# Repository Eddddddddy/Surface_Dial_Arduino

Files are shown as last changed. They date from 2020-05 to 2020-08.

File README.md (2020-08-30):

# Surface_Dial_Arduino

Use attiny85 to achieve surface dial function

## **！注意！建议使用/PCB_with_gerber/Pro/...attiny v2 github.zip！其他pcb工程（包含立创EDA的开源工程）未经本人测试，不做可靠性保证。**

将这个添加到你的Arduino IDE开发板中：http://digistump.com/package_digistump_index.json

/bom.xlsx ：元器件清单

/lib ：arduino库

/src ：arduino代码（包含融丝恢复器代码）

/tools ：编程器上位机软件

/stl model ：3D打印模型

/PCB_with_gerber ：pcb文件

立创EDA开源文件在[这里](https://oshwhub.com/Lingling0408/project-dial-pcb)

【点个Star！】谢谢！

在[这里](https://www.bilibili.com/video/BV17K411W78w/)可以查看视频介绍

------

| | Pro | Lite |
| --- | --- | --- |
| **O&M** | @Eddddddddy | @Eddddddddy, @leostudiooo |
| **Basic Functions** | Y | Y |
| **Cost** | Higher | Lower |
| **Vibration(Taptic Engine)** | Y | N |
| **Encoder** | EC11E1834403 _(ALPS, without detent)_ | EC11*(With detent)* |
| **Arduino File** | /src/Surface_Dial_attiny.ino | /src/Surface_Dial_attiny_Lite.ino |
| **PCB File** _(Now All-in-One)_ | /PCB_with_gerber/Pro | /PCB_with_gerber/Lite |
| **Fuse Reset** | Needed | Unnecessary |

------

你需要做什么？

- 想好购买的元器件是Pro还是Lite *（虽然后期也可以升级）*

- 在你信任的地方购买所需元器件

- 焊接（见/PCB_with_Gerber/README.md)

- 刷入程序

- 开始你的Dial之旅

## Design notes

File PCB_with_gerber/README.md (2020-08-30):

# 二合一版本未经本人测试

# 关于版本选择和焊接 Version Choice & Soldering

## **！建议使用/PCB_with_gerber/Pro/...attiny v2 github.zip！**

## 版本选择 Version Chioce

| | Pro | Lite |
| --- | --- | --- |
| **O&M** | @Eddddddddy | @Eddddddddy, @leostudiooo |
| **Basic Functions** | Y | Y |
| **Cost** | Higher | Lower |
| **Vibration(Taptic Engine)** | Y | N |
| **Encoder** | EC11E1834403 _(ALPS, without detent)_ | EC11*(With detent)* |
| **Arduino File** | /src/Surface_Dial_attiny.ino | /src/Surface_Dial_attiny_Lite.ino |
| **PCB File** _(Now All-in-One)_ | /PCB_with_gerber/Pro | /PCB_with_gerber/Lite |
| **Fuse Reset** | Needed | Unnecessary |

## PCB

你可以选择原版Pro或Lite，也可以尝试新出来的二合一版本。
You can choose the original Pro or Lite, or the 2 in 1 ver.

## 焊接 Soldering (for 2 in 1 ver.)

如果你选择二合一版本，那么你有升级的机会。
If you choose the 2 in 1(AIO) version, you have a chance to upgrade to Pro.

- 如果你选择Pro，请连接板子背面标注SW Pro的两个焊盘。
If you choose Pro, plz connect the two solders with "SW Pro" on the bottom.

- 如果你选择Lite，请连接板子正面标注SW Lite的两个焊盘。
If you choose Lite, plz connect the two solders with "SW Lite" on the top.

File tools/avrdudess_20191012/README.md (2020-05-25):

AVRDUDESS - A GUI for AVRDUDE
=============================

This is a GUI for AVRDUDE ([http://savannah.nongnu.org/projects/avrdude](http://savannah.nongnu.org/projects/avrdude)).

[https://blog.zakkemble.net/avrdudess-a-gui-for-avrdude/](https://blog.zakkemble.net/avrdudess-a-gui-for-avrdude/)

AVRDUDESS pic

Windows:
--------
Requires .NET Framework 2.0 SP1 or newer. All systems since Windows Vista will have the required version already installed.

Linux & macOS:
-----------------
Can be ran using Mono ([http://www.mono-project.com](http://www.mono-project.com)).\
Has not been tested on macOS, but should work. Might need the `--arch=32` argument.

    mono --arch=32 avrdudess.exe

Installing on Ubuntu 18.04:
---------------------------
Install Mono (this is the minimum required, you can use `mono-complete` for a full install):

    sudo apt-get install libmono-system-windows-forms4.0-cil

On older versions of Ubuntu you might need to use `libmono-winforms2.0-cil` instead.

Install AVRDUDE and AVR-GCC (for avr-size):

    sudo apt-get install avrdude gcc-avr

Run AVRDUDESS with mono, you might have to run as root (sudo) so that AVRDUDE can access ports if you haven't changed any permissions or rules.d stuff:

    mono avrdudess.exe

Building:
---------
You will need Microsoft Visual Studio 2015 or newer installed (older might work too). Open `./src/avrdudess.sln` and click the 'Start' button at the top and it will build and run AVRDUDESS.\
You can find the output in `./src/avrdudess/bin/Debug/`, or `./src/avrdudess/bin/Release/` if you chose to build for Release (the drop down box second from the left of the Start button is where you can choose the configuration).

Making the Installer:
---------------------
You will need [Inno Setup](http://www.jrsoftware.org/isinfo.php) installed. Once you've used Visual Studio to build the Release version of AVRDUDESS, run `./installer/installer.bat` and the installer exe will appear in the same directory.

--------

Zak Kemble

contact@zakkemble.net

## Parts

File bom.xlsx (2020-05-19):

元器件名 | 数量
attiny85-20su soic8 | 1
ec11e1834403 | 1
usb type-c 母座 16p 沉板1.6mm | 1
0603 自恢复保险丝 0.5A 6v | 1
s0805 J3Y 三极管 SOT-23 | 1
0603 1.5k电阻 | 1
0603 4.7k电阻 | 3
0603 5.1k电阻 | 2
0603 66.5欧电阻 | 2
0603 0.1uf 电容 | 1
0603 4.7uf 电容 | 1
1206 3.6v 齐纳二极管 | 2
M2*6 平头螺丝 | 3
M4*8 圆头螺丝 | 3
0.5mm 硅胶防滑垫 | 5*5cm
48mm 铝合金旋钮帽 | 1
iPhone 7 taptic engine 线性马达 | 1

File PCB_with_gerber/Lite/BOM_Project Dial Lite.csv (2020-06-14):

ID | Name | Designator | Footprint | Quantity | Manufacturer Part | Manufacturer | Supplier | Supplier Part | value | 3DModel
1 | Comment | U?,U?,U?,U? | JUMPER | 4 |  |  |  |  | Comment | Jumper_5mm
2 | 3.6 Zener | U?,U? | LL34 | 2 |  |  |  |  | 3.6 Zener | LL-34_BD1.5-L3.5
3 | 500ma | U? | 0603R | 1 |  |  |  |  | 500ma | CircuitWorks - 0603-Resistor
4 | 5.1k | U?,U? | 0603R | 2 |  |  |  |  | 5.1k | CircuitWorks - 0603-Resistor
5 | 4.7K | U?,U?,U? | 0603R | 3 |  |  |  |  | 4.7K | CircuitWorks - 0603-Resistor
6 | 1.5k | U? | 0603R | 1 |  |  |  |  | 1.5k | CircuitWorks - 0603-Resistor
7 | 66.5 | U?,U? | 0603R | 2 |  |  |  |  | 66.5 | CircuitWorks - 0603-Resistor
8 | 4.7uF | U? | 0603C | 1 |  |  |  |  | 4.7uF | 0603c 100nf
9 | 0.1uF | U? | 0603C | 1 |  |  |  |  | 0.1uF | 0603c 100nf
10 | TYPE_C | USB1 | TYPE-C_A | 1 |  |  |  |  | TYPE_C | USB-C_SMD-TYPE-C-31-M-12
11 | EC11E1834403 | EC1 | SW-TH_EC11E1820402 | 1 |  |  |  |  | EC11 | EC11-5
12 | attiny85 | * | SOP8W | 1 |  |  |  |  | attiny85 | SW3dPS-SOIC8_(ATTINY12)

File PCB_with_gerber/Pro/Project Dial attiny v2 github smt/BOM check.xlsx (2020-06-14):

check | Name | Designator | Footprint | Quantity | value
1 | 3.6 Zener | U?,U? | LL34 | 2 | 3.6 Zener
1 | 500ma | U? | 0603R | 1 | 500ma
1 | 5.1k | U?,U? | 0603R | 2 | 5.1k
1 | 4.7K | U?,U?,U? | 0603R | 3 | 4.7K
1 | 1.5k | U? | 0603R | 1 | 1.5k
1 | 66.5 | U?,U? | 0603R | 2 | 66.5
1 | 4.7uF | U? | 0603C | 1 | 4.7uF
1 | 0.1uF | U? | 0603C | 1 | 0.1uF
1 | attiny85 | * | SOP8W | 1 | attiny85
1 | 1K | R4 | 0603R | 1 | 1K
1 | S8050 | Q1 | SOT-23 | 1 | S8050
1 | EC11E1834403 | EC1 | SW-TH_EC11E1820402 | 1 | EC11E1834403
1 | TYPE_C | USB1 | TYPE-C_A | 1 | TYPE_C

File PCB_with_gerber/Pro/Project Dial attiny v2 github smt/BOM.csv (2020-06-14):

ID | Name | Designator | Footprint | Quantity | Manufacturer Part | Manufacturer | Supplier | Supplier Part | value | 3DModel
1 | Comment | U?,U?,U?,U?,U? | JUMPER | 5 |  |  |  |  | Comment | Jumper_5mm
2 | 3.6 Zener | U?,U? | LL34 | 2 |  |  |  |  | 3.6 Zener | CircuitWorks - 0603-Resistor
3 | 500ma | U? | 0603R | 1 |  |  |  |  | 500ma | CircuitWorks - 0603-Resistor
4 | 5.1k | U?,U? | 0603R | 2 |  |  |  |  | 5.1k | CircuitWorks - 0603-Resistor
5 | 4.7K | U?,U?,U? | 0603R | 3 |  |  |  |  | 4.7K | CircuitWorks - 0603-Resistor
6 | 1.5k | U? | 0603R | 1 |  |  |  |  | 1.5k | CircuitWorks - 0603-Resistor
7 | 66.5 | U?,U? | 0603R | 2 |  |  |  |  | 66.5 | CircuitWorks - 0603-Resistor
8 | 4.7uF | U? | 0603C | 1 |  |  |  |  | 4.7uF | 0603c 100nf
9 | 0.1uF | U? | 0603C | 1 |  |  |  |  | 0.1uF | 0603c 100nf
10 | attiny85 | * | SOP8W | 1 |  |  |  |  | attiny85 | SW3dPS-SOIC8_(ATTINY12)
11 | 1K | R4 | 0603R | 1 |  |  |  |  | 1K | CircuitWorks - 0603-Resistor
12 | S8050 | Q1 | SOT-23 | 1 |  |  |  |  | S8050 | SOT-23-3L_L2.9-W1.6-H1.1-LS2.8-P0.95
13 | EC11E1834403 | EC1 | SW-TH_EC11E1820402 | 1 |  |  |  |  | EC11E1834403
14 | TYPE_C | USB1 | TYPE-C_A | 1 |  |  |  |  | TYPE_C | USB-C_SMD-TYPE-C-31-M-12
15 | Taptic Engine | R3 | 1812R | 1 |  |  |  |  | Taptic Engine

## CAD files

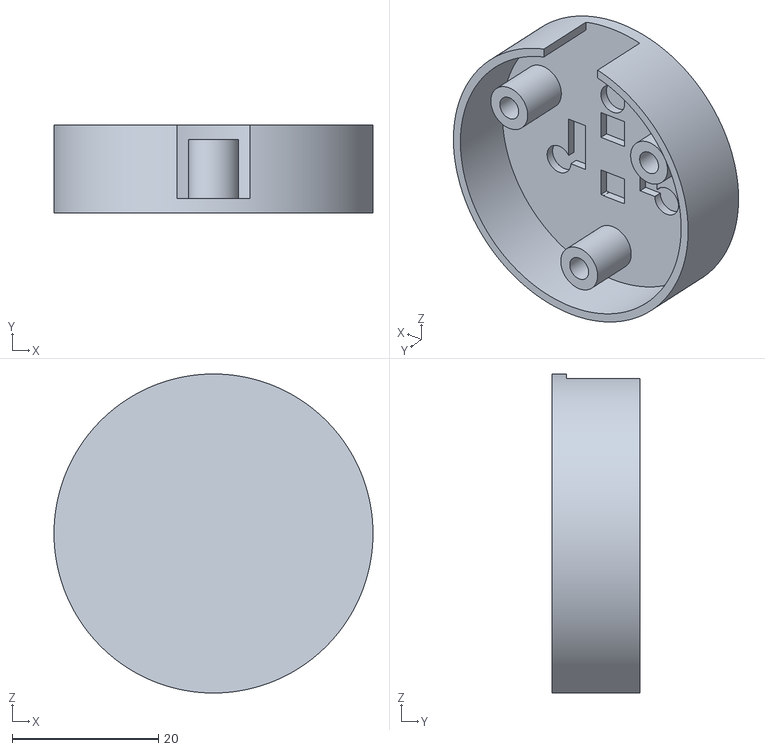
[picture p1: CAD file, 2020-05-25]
stl model/surface dial v2.3.STL
43.6 x 12.0 x 43.6

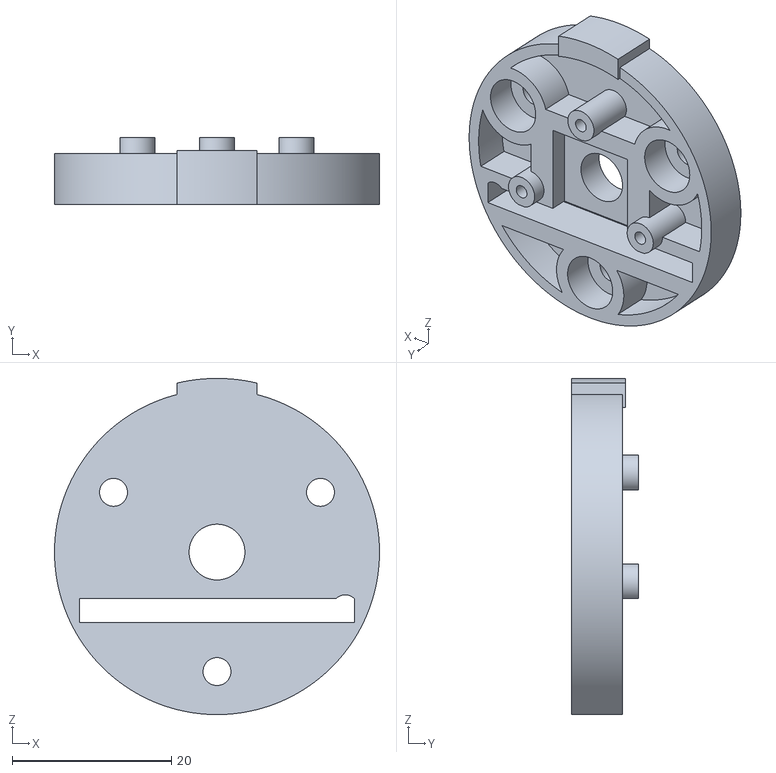
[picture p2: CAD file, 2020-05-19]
stl model/surface dial t v2.3.STL
40.8 x 8.40 x 42.2

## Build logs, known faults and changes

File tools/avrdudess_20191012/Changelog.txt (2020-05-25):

2019-10-12 (v2.11):
	- Fixed null exception if no MCU selected and "Set fuses" ticked
	- Updated Polish translation

2019-10-02 (v2.10):
	- Fix fuse read issue with MCUs that don't have all low, high and extended fuses
	- Update avrdude.conf to allow setting the CFD bit (Disable Clock Failure Detection) in the extended fuse for the ATmega328PB
	- Update URLs to HTTPS

2019-09-06 (v2.9):
	- Added French translation
	- Added Russian translation
	- Now shows full command line arguments in console output whenever avrdude is invoked
	- Fixed breaking click and drag anywhere to move window
	- Window title now shows "avrdude version UNKNOWN" instead of "?" if unable to find avrdude version

2019-02-09 (v2.8):
	- Added .NET 4.0+ to the list of supported runtimes, no longer need to install old .NET versions onto newer systems
	- Language selection box has been widened
	- New "About" box, now with clickable link
	- No longer creates temporary files when reading fuses and lock bits
	- LPT parallel port names in the port drop down box are now lower case
	- When resizing the main window, the controls on the right side are now also resized

2019-01-22 (v2.7):
	- Added Polish translation
	- Added Chinese translation
	- Added AVRDUDE support for ATmega328PB
	- Added displaying MCU signature near to the flash and EEPROM sizes
	- Fixed being unable to load xml file in the fuse bit selector window in Linux
	- Fixed flash and EEPROM file operation only being able to verify when a language other than English is chosen
	- All configuration settings are now saved across sessions instead of only the last selected preset
	- Window size is now saved across sessions
	- Use save file dialog when appropriate instead of only using an open file dialog

2018-09-20 (v2.6):
	- Fetch a different XML file when checking for updates as older versions of AVRDUDESS don't like the new format

2018-09-20 (v2.5):
	- Updated AVRDUDE to v6.3
	- libusb0.dll now included
	- Added a preset manager, you can export and import presets and manage existing presets much easier now
	- Added options to hide programmers and MCUs from their drop-down menus
	- Added support for different languages, translations go into an xml file in the Languages folder
	- Added avrdude support for ATtiny841, ATtiny441 and ATmega16U4
	- Added persistent window location, AVRDUDESS will now open in the same location that it was last closed
	- Added a preset for Arduino as ISP
	- Fixed flash and EEPROM usage bars not working if there is a space in the file path
	- Fixed form tab indexes, pressing tab will now go through form controls in order
	- When clicking the 'Fuse settings' link it will now automatically load up the selected MCU and fuse values
	- Most errors and warnings are now printed to the output console (in pretty colours!) instead of having a million pop-up boxes
	- Main window can now be properly resized
	- Improved avrdude.conf file parsing
	- Various other little fixes and improvements

2014-08-05 (v2.4):
	- For some reason antivirus software falsely detects AVRDUDESS as malware when using HttpWebRequest to check for updates, using raw sockets seems to fix it

2014-07-13 (v2.3):
	- Updated AVRDUDE to v6.1
	- USB option in port drop down list is now lower case
	- Automatically prepend 0x to fuse hex values
	- Fixed issue with spaces when setting avrdude.conf location

2014-01-02 (v2.2):
	- Fixed USBasp frequency not loading from presets for some users
	- Fixed incorrect fuse bits for ATmega328(P)
	- Flash and EEPROM sizes of selected MCU is shown
	- Flash and EEPROM space used is shown as a little usage bar above .hex/.eep file locations and in console
	- Fuse bit names have been moved to an external file (bits.xml)
	- Added options window
	- Now shows log if MCU autodetect failed

2013-11-20 (v2.1):
	- No longer need to run as administrator to have the config and presets save correctly
	- Fixed some typos
	- Some more under the hood improvements

2013-11-19 (v2.0):
	- Updated AVRDUDE to v6.0.1
	- Window title shows AVRDUDE version
	- AVRDUDE output console moved to main window
	- Preset to load at startup can be specified in the command line
	- Sticky presets (load last used preset at startup, if one hasn't been specified in the command line)
	- Auto detect MCU
	- Fuse selector
	- USBasp programmer frequency options
	- Tool tips setting now saves
	- "Update available" window now shows a change log
	- "Update available" window now has "Skip version" instead of "Don't ask again"
	- "Set fuses" checkbox now defaults to unchecked
	- Port selection in Linux now shows ttyS*, ttyUSB*, ttyACM* and lp* devices instead of just ttyS*
	- Buttons to separately write/read/verify the flash/EEPROM/fuses
	- Popups for saving and deleting presets have been removed, now you type the name into the presets box and save or select the preset to delete and delete it.
	- GUI redesign
	- Various under the hood improvements

2013-02-26 (v1.2):
	- ATmega328 non-P added back to avrdude.conf
	- Fixed reading high and low fuses the wrong way around
	- Fixed if a textbox is full, selecting its contents and typing to replace text didn't work
	- Fixed wonky console window in Linux
	- Added right click options to console window (only seems to work in Windows)

2013-02-25 (v1.1):
	- Now only requires .NET Framework 2.0 SP1 instead of 4.0
	- Updated AVRDUDE to v5.11.1 from MHV AVR Tools (http://www.makehackvoid.com/project/mhvavrtools)
	- Fixed having to copy avrdude binary in Linux/OSX
	- Added verbosity level option

2013-02-17 (v1.0):
	- Initial release

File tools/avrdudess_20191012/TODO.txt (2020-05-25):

Add: Better support for ATxmega devices (They have fuses 0-5 instead of low/high/extended and a few other things)
Add: Better fuse selector
Add: Compile avrdude with libftdi support
Add: Simple UI mode
Add: Options to run external programs before and after running AVRDUDE
Add: Accept the same command line arguments as AVRDUDE, which will then be applied to the UI
Fix: High verbosity level resulting in slow programming caused by slow console output
Fix: When auto-detecting MCU have a better guess at what programming interface to use (at the moment it only uses ISP or bootloader)

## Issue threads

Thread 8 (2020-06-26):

暂时没有支持正版Dial完整功能的原因(Reasons why we cannot achieve all of the functions of original Dial)

leostudiooo, 2020-06-26:
## 问题 _(Issue)_
目前暂不支持dial的完整功能。_(We cannot achieve all of the functions of original Dial.)_
## 原因（我猜的）_(Reasons)_
- 连接方式（次要）_(Connection method(Secondary))_
- 底部设计（主要）_(Bottom design(Primary))_
  - 尺寸问题（涉及到顶盖尺寸和顶盖的公益，这意味着我们没法买旋钮帽了。导致成本上升。）_(Size)_
  - 底部花纹（涉及到PixelSense对Dial物体的识别问题，若解决即可放在屏幕上使用并识别位置和尺寸，但导致成本上升。）_(Patterns on the bottom side(Has sth to do with PixelSense's object recognition))_
    - ***仅限Surface系列(Only for Surface Series)***

Eddddddddy, 2020-06-26:
对，因为所有的尺寸都是依据旋钮帽的直径，再大的旋钮帽需要定做，买不到现成的。
底部的那个防滑垫，的确是pixelsense，还没没进一步研究，因为只支持surface pro 4之后的surface pro 和 surface studio，感觉意义不大，没进一步研究。

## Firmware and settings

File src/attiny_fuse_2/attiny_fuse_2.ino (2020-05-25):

// HVSP-FUSE-resetter for attiny85 compatibles
// tested with attiny85 in both roles as rescuer and victim
// inspired by https://sites.google.com/site/wayneholder/attiny-fuse-reset
// as a reduced form of
// and http://www.rickety.us/wp-content/uploads/2010/03/hv_serial_prog.pde
// adapted to all informations from the data-sheet of attiny85 as
// both implementations differed.

// Version 3.0
// 14. August 2013 by gogol


// defining which PIN will be used for which role

#define  DATAIN   1   // Target Data Input
                  //->connect to PIN7 (SDO) via 1k resistor
                   // on-board-LED would indicate the result of fuseReset
#define  RST     5   // connect to 12V switch-Resistor for HVS-programming, 
                   // limited current of PB5 no problem for that purpose
                  //->connect via 10k resistor to basis of transistor to PIN1 (RST)
                   // Note: The Reset function on PB5 must be disabled, thus PB5 can be a GPIO to trigger reset on target chip.
#define  VCC     2   // Target VCC 
                  //->connect to PIN8 (Vcc) direct
#define  INSTOUT  4   // Target Instruction Input
                   // limited high of 3.6V because of zener no problem, as detected as high
                  //->connect to PIN6 (SII) via 1k resistor
                   // If PB4 is high during start-up, the whole chip would be erased to reset lockbits.Please release the key-swith after the twice-flash of the on-board-LED.
#define  CLKOUT   3   // Target Clock Input
                   // limited high of 3.6V because of zener and pullup no problem, as detected as high
                  //->connect to PIN2 (SCI) via 1k resistor
#define  DATAOUT  0   // Target Data Output
                  //->connect to PIN5 (SDI) via 1k resistor

// fuses for attiny85 digispark-compatibel use, without RSTDISBL
// avrdude parameters: -U lfuse:w:0xe1:m -U hfuse:w:0xdd:m -U efuse:w:0xfe:m
#define  HFVAL  0xdf
#define  LFVAL  0xf1
#define  EFVAL  0xfe

// byte constants for HVSP-programming instructions
// see attiny85 datasheet table 20-16
#define _0_0000_0000_00 0b00000000
#define _0_0000_0100_00 0b00000100
#define _0_0000_1000_00 0b00001000
#define _0_0000_1100_00 0b00001100
#define _0_0010_1100_00 0b00101100
#define _0_0100_0000_00 0b01000000
#define _0_0100_1100_00 0b01001100
#define _0_0110_0100_00 0b01100100
#define _0_0110_0110_00 0b01100110
#define _0_0110_1000_00 0b01101000
#define _0_0110_1010_00 0b01101010
#define _0_0110_1100_00 0b01101100
#define _0_0110_1110_00 0b01101110
#define _0_0111_0100_00 0b01110100
#define _0_0111_1000_00 0b01111000
#define _0_0111_1010_00 0b01111010
#define _0_0111_1100_00 0b01111100
#define _0_0111_1110_00 0b01111110
#define _0_1000_0000_00 0b10000000


boolean fuse_ok      = false;
boolean lock_bit_set = false;
boolean eraseChip    = false;

void setup() {
  // all work is done in setup()
  // fuse resetting either works or fails
  // The following instructions are from the datasheet:
  // 1. Set Prog_enable pins listed in Table 20-14 to “000”, RESET pin and VCC to 0V.
  // 2. Apply 4.5 - 5.5V between VCC and GND. Ensure that VCC reaches at least 1.8V within the next 20 μs.
  // 3. Wait 20 - 60 μs, and apply 11.5 - 12.5V to RESET.
  // 4. Keep the Prog_enable pins unchanged for at least 10 μs after the High-voltage has been applied to
  //   ensure the Prog_enable Signature has been latched.
  // 5. Release the Prog_enable[2] pin to avoid drive contention on the Prog_enable[2]/SDO pin.
  // 6. Wait at least 300 μs before giving any serial instructions on SDI/SII.
  // 7. Exit Programming mode by power the device down or by bringing RESET pin to 0V.

  
  pinMode(VCC, OUTPUT); 
  digitalWrite(VCC, LOW);      // make sure, no +5V on target
  pinMode(RST, OUTPUT);
  digitalWrite(RST, HIGH);     // transistor is inverting signal, this shuts off 12V
  pinMode(CLKOUT, OUTPUT);
  digitalWrite(CLKOUT, LOW);   
  pinMode(DATAOUT, OUTPUT);    
  digitalWrite(DATAOUT, LOW);
  pinMode(DATAIN, OUTPUT);     // temporary for fullfilling 1.)
  digitalWrite(DATAIN, HIGH); 
 delay(50);
  digitalWrite(DATAIN, LOW);
 delay(100);
  digitalWrite(DATAIN, HIGH);
 delay(50);
  digitalWrite(DATAIN, LOW);  // Flash twice to indicate Bootloader over and fuseReset process start

  pinMode(INSTOUT, INPUT);
  if (digitalRead(INSTOUT)) {
    eraseChip = true;        // when INSTOUT is high at startup, the whole chip should be erased to reset lockbits. 
  };
  while (digitalRead(INSTOUT)); // make sure, the key is not longer pressed.
 delay(500);

  pinMode(INSTOUT, OUTPUT);     // now set INSTOUT as well to OUTPUT!
  digitalWrite(INSTOUT, LOW);

  digitalWrite(VCC, HIGH);     // 2.) switch target Vcc on
 delayMicroseconds(50);
  digitalWrite(RST, LOW);      // 3.) 12v powered ON
  delayMicroseconds(15);       // 4.)
  pinMode(DATAIN, INPUT);      // 5.) Set DATAIN to input
  delayMicroseconds(330);      // 6.)
  if (eraseChip) {
   chipErase();
  }  
  if (( 0b00000110 & readLockBits()) != 0b00000110) {
   lock_bit_set = true; 
  }  else {
   writeFuse(LFVAL, _0_0110_0100_00, _0_0110_1100_00);
   writeFuse(HFVAL, _0_0111_0100_00, _0_0111_1100_00);
   writeFuse(EFVAL, _0_0110_0110_00, _0_0110_1110_00);
    fuse_ok = checkFuses();
  }  

  digitalWrite(CLKOUT, LOW);
  digitalWrite(VCC, LOW);      // 7.) 
  digitalWrite(RST, HIGH);     //    
  pinMode(DATAIN, OUTPUT);     // change to output, so loop can blink codes
  digitalWrite(DATAIN, LOW); 

 
}

void clockPulse() {
  digitalWrite(CLKOUT, HIGH);
  digitalWrite(CLKOUT, LOW); 
}  

int hvsp_bytes_out( byte val, byte val1)
{
  int inBits = 0;
  // Wait until DATAIN goes high
  while (!digitalRead(DATAIN));  // now we are ready
  // each instruction command has 11 clock pulses
  // one before each of the 8bits, one after each bit, two after each byte
  //initial clock pulse while DATAOUT and INSTOUT LOW
  digitalWrite(DATAOUT, LOW);
  digitalWrite(INSTOUT, LOW);
 clockPulse();
  int i;
  // now the 8 databits
  for (i = 0; i < 8; i++)  {
   digitalWrite(DATAOUT, !!(val & (1 << (7 - i))));
   digitalWrite(INSTOUT, !!(val1 & (1 << (7 - i))));
    // a given return byte starts one bit before output bits!
    // therefore reading it before clock-pulse for out
    inBits <<=1;
    inBits |= digitalRead(DATAIN);
   clockPulse();  
  }
  // after each byte-group (one byte to DATAOUT and INSTOUT in parallel)
  // two clock-pulses with DATAOUT and INSTOUT LOW
  digitalWrite(DATAOUT, LOW);
  digitalWrite(INSTOUT, LOW);
 clockPulse();
 clockPulse();
  // return the 8-bits read 
  // interpretation see datasheet
  return inBits;
}

void writeFuse( byte value, byte instrc3, byte instrc4) {
  hvsp_bytes_out( _0_0100_0000_00, _0_0100_1100_00);
  hvsp_bytes_out( value,         _0_0010_1100_00);
  hvsp_bytes_out( _0_0000_0000_00, instrc3);
  hvsp_bytes_out( _0_0000_0000_00, instrc4);
  // Wait after Instr. 4 until SDO goes high
  while (!digitalRead(DATAIN));
}  

byte readFuse(byte instrc2, byte instrc3) {
  hvsp_bytes_out( _0_0000_0100_00, _0_0100_1100_00);
  hvsp_bytes_out( _0_0000_0000_00, instrc2);
  return hvsp_bytes_out( _0_0000_0000_00, instrc3);
}  

byte readLockBits( ) {
  hvsp_bytes_out( _0_0000_0100_00, _0_0100_1100_00);
  hvsp_bytes_out( _0_0000_0000_00, _0_0111_1000_00);
  return hvsp_bytes_out( _0_0000_0000_00, _0_0111_1100_00);
}  

void chipErase( ) {
  hvsp_bytes_out( _0_1000_0000_00, _0_0100_1100_00);
  hvsp_bytes_out( _0_0000_0000_00, _0_0110_0100_00);
  hvsp_bytes_out( _0_0000_0000_00, _0_0110_1100_00);
  // Wait after Instr. 3 until SDO goes high
  while (!digitalRead(DATAIN));
}  

boolean checkFuses () {
  if (LFVAL != readFuse(_0_0110_1000_00, _0_0110_1100_00)) {
    return false; 
  }  
  if (HFVAL != readFuse(_0_0111_1010_00, _0_0111_1110_00)) {
    return false; 
  }  
  // the only guaranteed value is the first bit
  // all other values the datasheet tells: "don't care!"
  if ((0b00000001 & EFVAL) != ( 0b00000001 &  readFuse(_0_0110_1010_00, _0_0110_1110_00))) {
    return false; 
  }  
  return true;
}


void loop() {
  if (fuse_ok) { // LED keeps on, when fusing was ok
     digitalWrite(DATAIN, HIGH); 
  } else if (lock_bit_set) {
     digitalWrite(DATAIN, HIGH); // LED blinking slowly, when lock-bit set. If you want to reset the lockbits and erase the chip, You need to press the key-swith at power-up, then release after the twice-flash of the on-board-LED.
     delay(1000);
     digitalWrite(DATAIN, LOW); 
     delay(1000);
  } else {
     digitalWrite(DATAIN, HIGH); // LED blinking rapidly, when error in fusing
     delay(50);
     digitalWrite(DATAIN, LOW); 
     delay(50);
  }  
}  // Note : on-board-LED would not burn or flash when target chip don't respond.  e.g. condition like bad chip or low voltage of 12V.

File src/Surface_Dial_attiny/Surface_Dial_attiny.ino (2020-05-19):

#include "TrinketHidCombo.h"

#define PIN_ENCODER_A 2
#define PIN_ENCODER_B 1
#define TRINKET_PINx  PINB
#define PIN_ENCODER_SWITCH 5
#define TAPTIC 0

static uint8_t enc_prev_pos   = 0;
static uint8_t enc_flags      = 0;
static char    sw_was_pressed = 0;


int speed_r = 3;
uint8_t rotate_r_R = DIAL_R;
uint8_t rotate_r_L = DIAL_L;
int Taptic_r = 3;

volatile bool previousButtonValue = false, lastButtonValue = false;

volatile int previous = 0;
volatile int counter = 0;

long debounceDelay = 50;
long lastDebounceTime = 0;

long lastDouble = 0;
long nowDouble = 0;
long ddlDouble=500;



void setup()
{
  // set pins as input with internal pull-up resistors enabled
  pinMode(PIN_ENCODER_A, INPUT);
  pinMode(PIN_ENCODER_B, INPUT);
//  digitalWrite(PIN_ENCODER_A, HIGH);
//  digitalWrite(PIN_ENCODER_B, HIGH);

  pinMode(TAPTIC, OUTPUT);

  pinMode(PIN_ENCODER_SWITCH, INPUT);
  // the switch is active-high, not active-low
  // since it shares the pin with Trinket's built-in LED
  // the LED acts as a pull-down resistor
//  digitalWrite(PIN_ENCODER_SWITCH, LOW);

  TrinketHidCombo.begin(); // start the USB device engine and enumerate

  // get an initial reading on the encoder pins
  if (digitalRead(PIN_ENCODER_A) == LOW) {
    enc_prev_pos |= (1 << 0);
  }
  if (digitalRead(PIN_ENCODER_B) == LOW) {
    enc_prev_pos |= (1 << 1);
  }
}


void doubleClick() {
  if (rotate_r_R == DIAL_R) {
    rotate_r_R = DIAL_R_F;
    rotate_r_L = DIAL_L_F;
    speed_r = 1;
    Taptic_r = 1;
    digitalWrite(TAPTIC, HIGH);
    delay(3);
    digitalWrite(TAPTIC, LOW);
    delay(200);
    digitalWrite(TAPTIC, HIGH);
    delay(3);
    digitalWrite(TAPTIC, LOW);
  } else if (rotate_r_R == DIAL_R_F) {
    rotate_r_R = DIAL_R;
    rotate_r_L = DIAL_L;
    speed_r = 3;
    Taptic_r = 3;
    digitalWrite(TAPTIC, HIGH);
    delay(3);
    digitalWrite(TAPTIC, LOW);
    delay(200);
    digitalWrite(TAPTIC, HIGH);
    delay(3);
    digitalWrite(TAPTIC, LOW);
  }
}

void loop()
{
  int8_t enc_action = 0; // 1 or -1 if moved, sign is direction

  // note: for better performance, the code will now use
  // direct port access techniques
  // http://www.arduino.cc/en/Reference/PortManipulation
  uint8_t enc_cur_pos = 0;
  // read in the encoder state first
  if (bit_is_clear(TRINKET_PINx, PIN_ENCODER_A)) {
    enc_cur_pos |= (1 << 0);
  }
  if (bit_is_clear(TRINKET_PINx, PIN_ENCODER_B)) {
    enc_cur_pos |= (1 << 1);
  }

  // if any rotation at all
  if (enc_cur_pos != enc_prev_pos)
  {
    if (enc_prev_pos == 0x00)
    {
      // this is the first edge
      if (enc_cur_pos == 0x01) {
        enc_flags |= (1 << 0);
      }
      else if (enc_cur_pos == 0x02) {
        enc_flags |= (1 << 1);
      }
    }

    if (enc_cur_pos == 0x03)
    {
      // this is when the encoder is in the middle of a "step"
      enc_flags |= (1 << 4);
    }
    else if (enc_cur_pos == 0x00)
    {
      // this is the final edge
      if (enc_prev_pos == 0x02) {
        enc_flags |= (1 << 2);
      }
      else if (enc_prev_pos == 0x01) {
        enc_flags |= (1 << 3);
      }

      // check the first and last edge
      // or maybe one edge is missing, if missing then require the middle state
      // this will reject bounces and false movements
      if (bit_is_set(enc_flags, 0) && (bit_is_set(enc_flags, 2) || bit_is_set(enc_flags, 4))) {
        enc_action = 1;
      }
      else if (bit_is_set(enc_flags, 2) && (bit_is_set(enc_flags, 0) || bit_is_set(enc_flags, 4))) {
        enc_action = 1;
      }
      else if (bit_is_set(enc_flags, 1) && (bit_is_set(enc_flags, 3) || bit_is_set(enc_flags, 4))) {
        enc_action = -1;
      }
      else if (bit_is_set(enc_flags, 3) && (bit_is_set(enc_flags, 1) || bit_is_set(enc_flags, 4))) {
        enc_action = -1;
      }

      enc_flags = 0; // reset for next time
    }
  }

  enc_prev_pos = enc_cur_pos;

  if (enc_action > 0) {
        TrinketHidCombo.pressMultimediaKey(rotate_r_R);
        //Serial.println("R");
        //counter -= speed_r;
        digitalWrite(TAPTIC, HIGH);
        delay(Taptic_r);
        digitalWrite(TAPTIC, LOW);
  }
  else if (enc_action < 0) {
    TrinketHidCombo.pressMultimediaKey(rotate_r_L);
        //Serial.println("L");
        //counter += speed_r;
        digitalWrite(TAPTIC, HIGH);
        delay(Taptic_r);
        digitalWrite(TAPTIC, LOW);
  }

//  // remember that the switch is active-high
  if (bit_is_set(TRINKET_PINx, PIN_ENCODER_SWITCH)) 
  {
    if (sw_was_pressed == 0) // only on initial press, so the keystroke is not repeated while the button is held down
    {
      TrinketHidCombo.pressMultimediaKey(DIAL_RELEASE);
      delay(50); // debounce delay
    }
    sw_was_pressed = 1;
  }
  else
  {
    if (sw_was_pressed != 0) {
      TrinketHidCombo.pressMultimediaKey(DIAL_PRESS);
      delay(50); // debounce delay
              lastDouble = nowDouble;
        nowDouble = millis();
        if((nowDouble-lastDouble)<ddlDouble){
          doubleClick();
          nowDouble=0;
        }
    }
    sw_was_pressed = 0;
  }

//bool buttonValue = digitalRead(PIN_ENCODER_SWITCH);
//  bool buttonValue = bit_is_set(TRINKET_PINx, PIN_ENCODER_SWITCH);
//  if (buttonValue != lastButtonValue) {
//    lastDebounceTime = millis();
//  }
//  if ((millis() - lastDebounceTime) > debounceDelay) {
//    if (buttonValue != previousButtonValue) {
//      previousButtonValue = buttonValue;
//      if (buttonValue) {
//        TrinketHidCombo.pressMultimediaKey(DIAL_PRESS);
//          digitalWrite(TAPTIC,HIGH);
//          delay(Taptic_r);
//          digitalWrite(TAPTIC,LOW);
//        lastDouble = nowDouble;
//        nowDouble = millis();
//        if((nowDouble-lastDouble)<ddlDouble){
//          doubleClick();
//          nowDouble=0;
//        }
//      } else {
//        TrinketHidCombo.pressMultimediaKey(DIAL_RELEASE);
//
//      }
//    }
//  }

  

  TrinketHidCombo.poll(); // check if USB needs anything done
}

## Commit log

2020-05-19 add pcb
2020-05-19 add stl
    [surface dial t v2.3.STL, surface dial v2.2.STL]
2020-05-19 add bom
    [bom.xlsx]
2020-05-25 update stl model v2.3
    [surfacedialv2.3.STL]
2020-05-25 Delete surfacedialv2.3.STL
    reupdate
    [surfacedialv2.3.STL]
2020-05-25 add fuse recovery
2020-06-01 added LCEDA readable pcb file
    [Copy of Project Dial MLB.PcbDoc]
2020-06-01 update pcb file
    [Copy of Project Dial MLB.PcbDoc]
2020-06-07 gerber and BOM and P&P files(for SMT) added
    [BOM.csv, PCB_Project1.PrjPCB, PickAndPlace.csv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]
2020-06-07 Files readable for LCEDA added
    [Copy of Project Dial MLB.PcbDoc]
2020-06-07 update pr
    [BOM.csv, Copy of Project Dial MLB.PcbDoc, PCB_Project1.PrjPCB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]
2020-06-07 gerber and pcb re-upload
    [Copy of Project Dial MLB.PcbDoc]
2020-06-07 pcb re-upload
2020-06-07 LCEDA PCB File
2020-06-07 PCB and SMT cleaned
    [BOM.csv, Copy of Project Dial MLB.PcbDoc, PCB_Project1.PrjPCB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]
2020-06-07 renamed files
    [Project Dial MLB attiny.PcbDoc]
2020-06-14 Lite Edition Released Co-author: @Eddddddddy @luotr
    [BOM check.xlsx, BOM.csv]
2020-06-14 Lite Edition Released
    [BOM check.xlsx, BOM.csv, BOM_Project Dial Lite.csv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]
